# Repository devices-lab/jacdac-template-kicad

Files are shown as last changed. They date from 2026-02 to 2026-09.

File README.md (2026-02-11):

# jacdac-template-kicad

Jacdac RGB module KiCad project files for use as a template when creating new Jacdac modules. 

Based on Altium schematics from the [jacdac-ddk](https://github.com/jacdac/jacdac-ddk) and the [Jacdac KiCad library](https://github.com/mac-aron/jacdac-kicad).

#### Usage
- The script `library/convert.sh` can be used to download component symbols and footprints from LCSC (JLCPCB).
- The jobfile `export-fab-files.kicad_jobset` generates fabrication files to `gerbers/` with the correct settings
  - The column names in the CPL (component placement list) are incorrect for JLCPCB

Check the [neopixel-gerbersockets](../../tree/neopixel-gerbersockets) branch for a version with GerberSockets added.

> [!NOTE]
> The hardware has not been tested yet





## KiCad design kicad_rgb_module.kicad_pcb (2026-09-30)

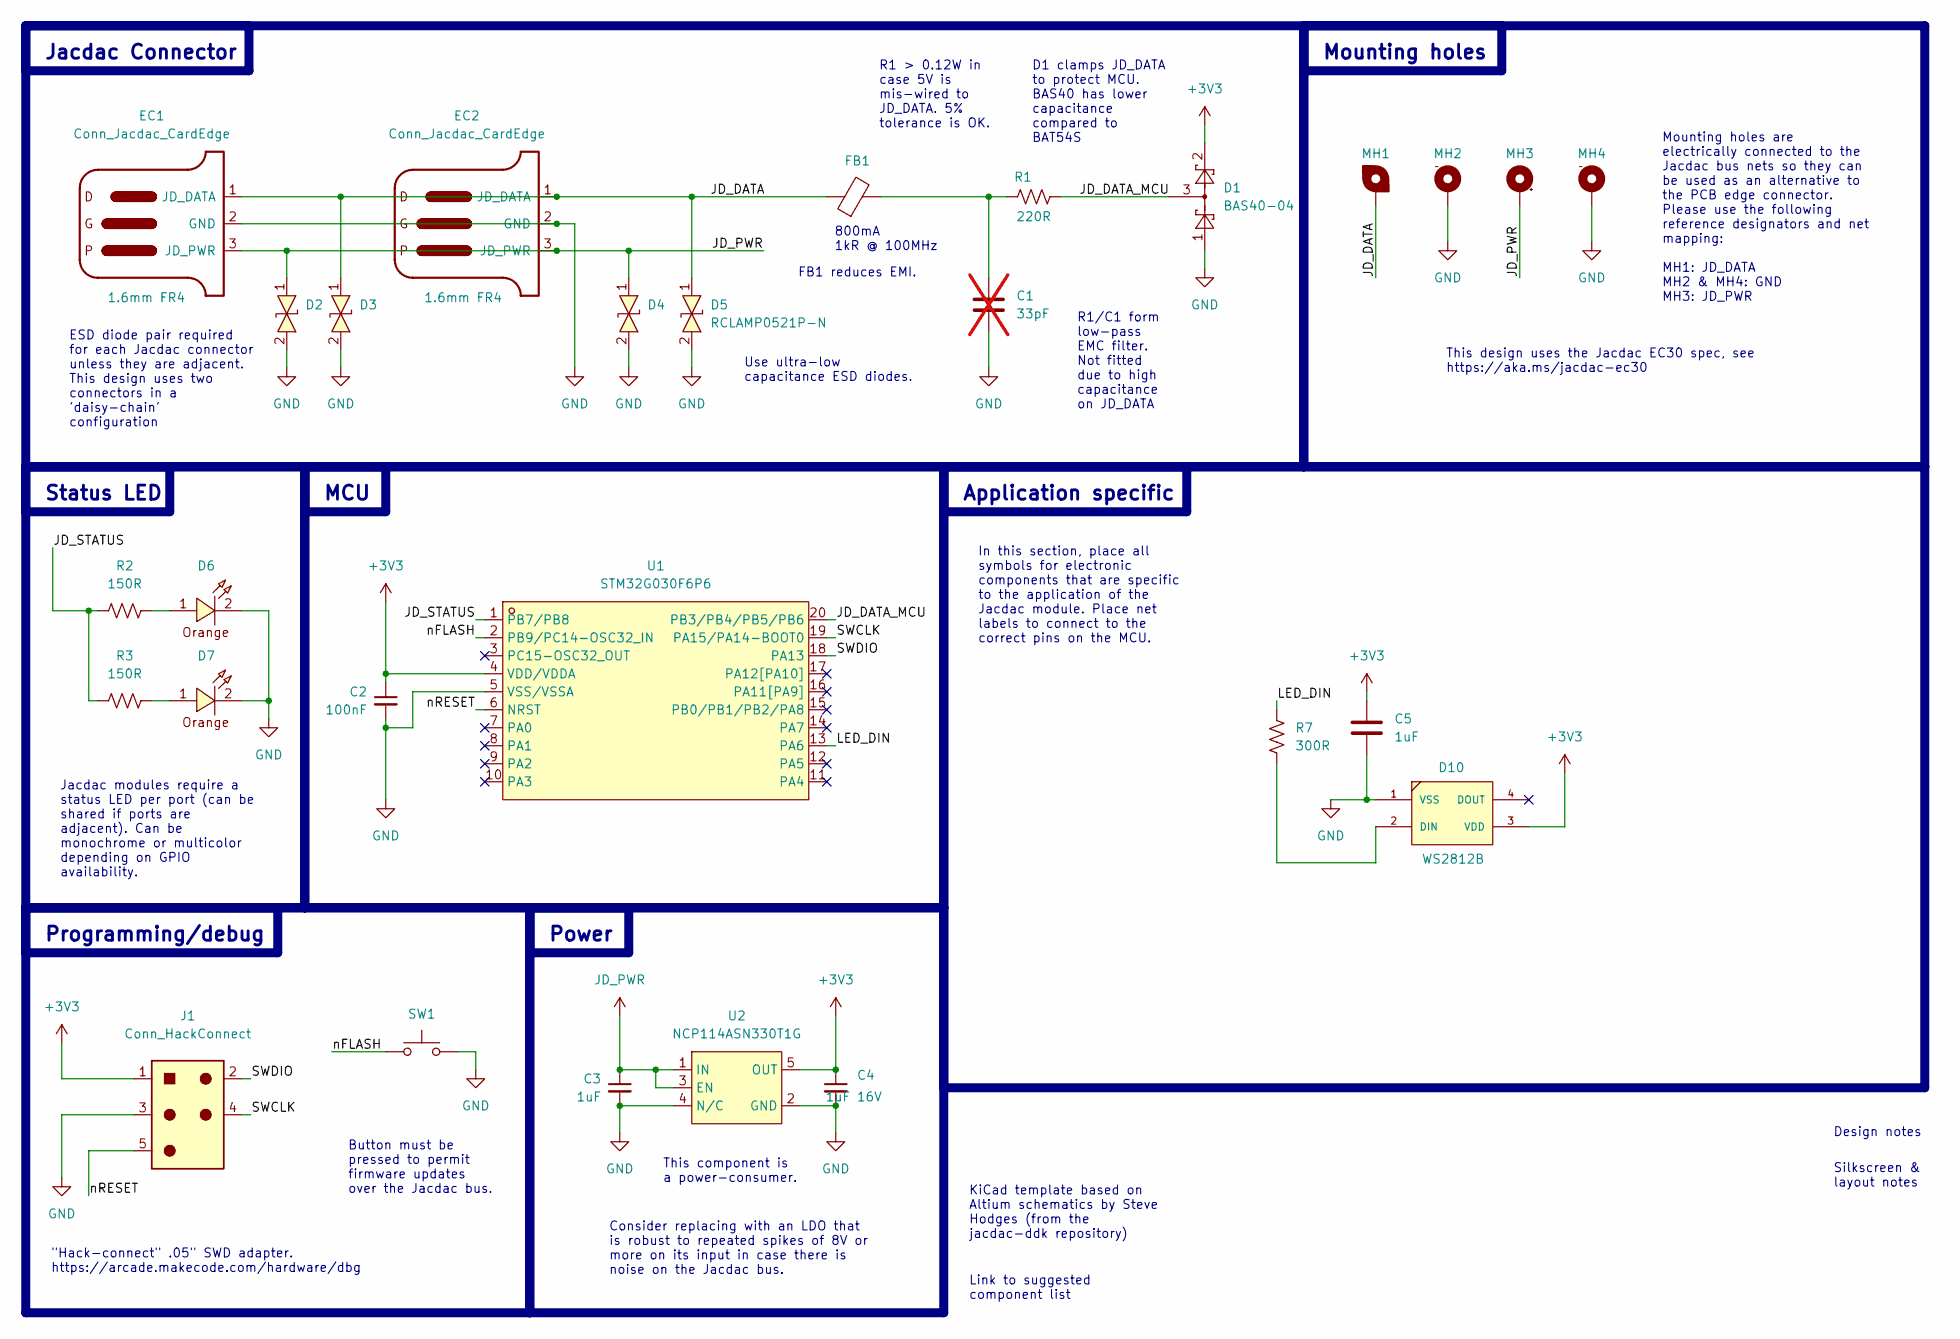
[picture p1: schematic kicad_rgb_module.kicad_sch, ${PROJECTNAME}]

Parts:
C1: 33pF; C_0603_1608Metric; LCSC Part C1663; not fitted
C2: 100nF; C_0603_1608Metric; LCSC Part C14663
C3, C5: 1uF; C_0603_1608Metric; LCSC Part C15849
C4: 1uF 16V; C_0603_1608Metric; LCSC Part C15849
D1: BAS40-04; SOT-23; LCSC Part C7502688
D2, D3, D4, D5: RCLAMP0521P-N; X1-DFN1006-2_L1.0-W0.6-P0.65-BI; LCSC Part C316043
D6, D7: SZYY0603O; LED0603-R-RD_ORANGE; LCSC Part C965800
D10: WS2812B; NeoPixel_WS2812B; Part type Extended; LCSC Part C2843785
EC1, EC2: Conn_Jacdac_CardEdge; JD-PEC-02_Prerouted_recessed
FB1: L0603; LCSC Part C1002
J1: Conn_HackConnect; HackConnect_P1.27mm
MH1: jacdac_hole_DATA_MH1
MH2: jacdac_hole_GND_MH2
MH3: jacdac_hole_PWR_MH3
MH4: jacdac_hole_GND_MH4
R1: 220R; R_0603_1608Metric; LCSC Part C22962
R2, R3: 150R; R_0603_1608Metric; LCSC Part C22808
R7: 300R; R_0603_1608Metric; LCSC Part C23025
SW1: TS-1088-AR02016; SW-SMD_L3.9-W3.0-P4.45; LCSC Part C720477
U1: STM32G030F6P6; TSSOP-20_L6.5-W4.4-P0.65-LS6.4-BL; LCSC Part C724040
U2: NCP114ASN330T1G; TSOP-5_L3.0-W1.5-P0.95-BL; LCSC Part C457666

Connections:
+3V3: C2.1, C4.1, C5.2, D1.2, D10.3 (VDD), J1.1, U1.4 (VDD/VDDA), U2.5 (OUT)
/JD_DATA: D3.1, D5.1, EC1.1 (JD_DATA), EC2.1 (JD_DATA), FB1.1, MH1.MH1
/JD_DATA_MCU: D1.3, R1.2, U1.20 (PB3/PB4/PB5/PB6)
/JD_STATUS: R2.1, R3.1, U1.1 (PB7/PB8)
/LED_DIN: R7.1, U1.13 (PA6)
/SWCLK: J1.4, U1.19 (PA15/PA14-BOOT0)
/SWDIO: J1.2, U1.18 (PA13)
/nFLASH: SW1.1, U1.2 (PB9/PC14-OSC32_IN)
/nRESET: J1.5, U1.6 (NRST)
GND: C1.2, C2.2, C3.2, C4.2, C5.1, D1.1, D2.2, D3.2, D4.2, D5.2, D6.2, D7.2, D10.1 (VSS), EC1.2 (GND), EC2.2 (GND), J1.3, MH2.MH2, MH4.MH4, SW1.2, U1.5 (VSS/VSSA), U2.2 (GND), U2.4 (N/C)
JD_PWR: C3.1, D2.1, D4.1, EC1.3 (JD_PWR), EC2.3 (JD_PWR), MH3.MH3, U2.1 (IN), U2.3 (EN)
unnamed: C1.1, FB1.2, R1.1
unnamed: D6.1, R2.2
unnamed: D7.1, R3.2
unnamed: D10.2 (DIN), R7.2

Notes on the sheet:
Mounting holes
Status LED
Programming/debug
MCU
800mA 1kR @ 100MHz
Application specific
Power
Jacdac Connector
Use ultra-low capacitance ESD diodes.
D1 clamps JD_DATA to protect MCU. BAS40 has lower capacitance compared to BAT54S
This component is a power-consumer.
KiCad template based on Altium schematics by Steve Hodges (from the jacdac-ddk repository)
Jacdac modules require a status LED per port (can be shared if ports are adjacent). Can be monochrome or multicolor depending on GPIO availability.
Design notes
ESD diode pair required for each Jacdac connector unless they are adjacent. This design uses two connectors in a 'daisy-chain' configuration
Mounting holes are electrically connected to the Jacdac bus nets so they can be used as an alternative to the PCB edge connector. Please use the following reference designators and net mapping: MH1: JD_DATA MH2 & MH4: GND MH3: JD_PWR
Link to suggested component list
R1/C1 form low-pass EMC filter. Not fitted due to high capacitance on JD_DATA
This design uses the Jacdac EC30 spec, see https://aka.ms/jacdac-ec30
In this section, place all symbols for electronic components that are specific to the application of the Jacdac module. Place net labels to connect to the correct pins on the MCU.
Button must be pressed to permit firmware updates over the Jacdac bus.
FB1 reduces EMI.
Silkscreen & layout notes
R1 > 0.12W in case 5V is mis-wired to JD_DATA. 5% tolerance is OK.
Consider replacing with an LDO that is robust to repeated spikes of 8V or more on its input in case there is noise on the Jacdac bus.
"Hack-connect" .05" SWD adapter. https://arcade.makecode.com/hardware/dbg

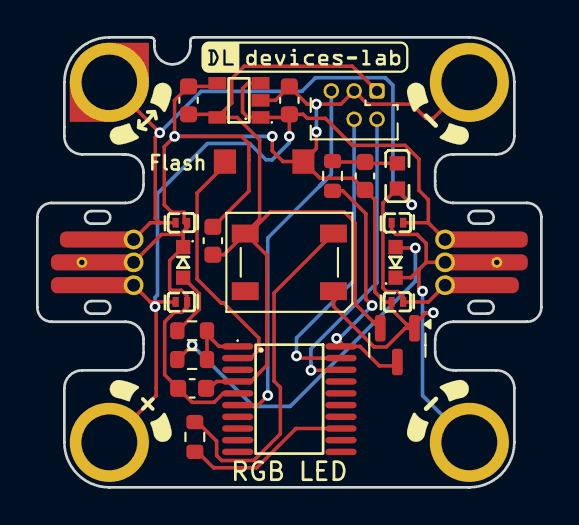
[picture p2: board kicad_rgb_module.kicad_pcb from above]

Board: 2 copper layers, 28.0 x 25.0 mm, 28 parts (0 on the bottom side), 15 nets.

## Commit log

2026-01-21 Add rgb_module project files (needs cleaning up to be a good template)
    [kicad_rgb_module.kicad_pcb, kicad_rgb_module.kicad_sch]
2026-01-21 Create README.md for Jacdac template project
    Add README for Jacdac RGB module KiCad template
2026-01-29 Add diode to nRESET, decide on board sides for GerberSockets
    [kicad_rgb_module.kicad_pcb, kicad_rgb_module.kicad_sch]
2026-01-30 Swap sides of GerberSockets, add devices-lab logo and hwidx QR code
    [kicad_rgb_module.kicad_pcb]
2026-02-02 Set the correct LCSC components
    [kicad_rgb_module.csv, kicad_rgb_module.kicad_pcb]
2026-02-02 Change some GerberSockets and components
    [kicad_rgb_module.csv, kicad_rgb_module.kicad_pcb, kicad_rgb_module.kicad_sch]
2026-02-03 Add test points
    [kicad_rgb_module.kicad_pcb, kicad_rgb_module.kicad_sch]
2026-02-03 Change design to use neopixel-style LED instead of regular RGB LED
    [kicad_rgb_module.kicad_pcb, kicad_rgb_module.kicad_sch]
2026-02-03 Fix pin order and footprint of neopixel-style LED
    [kicad_rgb_module.kicad_pcb, kicad_rgb_module.kicad_sch]
2026-02-05 Change BAT54 to BAS40-04 to reduce capacitance on JD_DATA
    [kicad_rgb_module.kicad_pcb, kicad_rgb_module.kicad_sch]
2026-02-11 Remove GerberSockets to simplify the template, replace QR code with placeholder
    [kicad_rgb_module.kicad_pcb, kicad_rgb_module.kicad_sch]
2026-02-11 fix last commit
    [kicad_rgb_module.kicad_pcb]
2026-02-11 Add jobfile for export, remove unused libs, leftover nets and traces in schematic and PCB
    [kicad_rgb_module.kicad_pcb, kicad_rgb_module.kicad_sch]
2026-02-11 Add refdes for each component on fab layer
    [kicad_rgb_module.kicad_pcb]
2026-09-30 Jobset: clean gerbers dir, fix CPL columns for JLCPCB, zip output
    Delete gerbers/ before exporting so stale files can't be used, then a
    second output renames the CPL header to JLCPCB names and zips gerbers/
    into ${PROJECTNAME}-gerbers.zip. Steps are inline python -c commands
    so no external script is needed. BOM/CPL outputs are now named
    ${PROJECTNAME}-BOM.csv / ${PROJECTNAME}-CPL.csv.
2026-09-30 Update PCB layout (pad UUID regenerated by KiCad)
    [kicad_rgb_module.kicad_pcb]
2026-09-30 Jobset: JLCPCB BOM column names, gerbers-<project>.zip, clearer CPL error
    Rename BOM headers to Comment/Designator/LCSC Part for JLCPCB upload,
    name the zip gerbers-${PROJECTNAME}.zip, and make the CPL rename step
    exit with a clear message when no CPL csv is found. Also picks up new
    keys written by a newer KiCad version.
